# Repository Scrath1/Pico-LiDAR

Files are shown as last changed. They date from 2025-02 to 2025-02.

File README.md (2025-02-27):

# Pico-LiDAR
The goal of this project is to build a simple LiDAR sensor using hobbyist components
such as the Raspberry Pi Pico microcontroller, VL53L0X Time-of-Flight laser sensor
and the HC-SR04P ultrasonic sensor.



## Bill of Materials (BOM)
<details>
<summary>Mechanical Parts (click to open)</summary>

- 608Z bearing
- generic 6 wire slip ring with 12.5mm diameter
- 7x M4x10 bolts (can be shorter)
- 6x M3x16 countersunk bolts (can be shorter) for mounting the dome top cover
  and the base bottom plate to their respective bodies.
- 7-8x M3x4 bolts for mounting the L298N and XL6009 to the base plate as well as the
  slipring to the axis mount.
  but you don't really need to use them all. The remaining screws are for the XL6009.
- 4x M2x6 bolts for mounting the perfboard
- 2-4x M2x4 bolts for mounting the Pi Pico
- 2x M4 nuts
  I used one with a 9mm contracted length (measured without the end rings) and a
  filament diameter of 0.5mm. Stronger springs are also possible but it should
  not be much longer.
- 5x M4x8x6mm threaded insert
- 6x M3x6x5mm threaded insert
- 1x rubber band
- (optional) 1x short tension spring.
- 5x cylindrical magnets 10x6mm. If you want to use different magnets feel
  free to modify the provided 3D files. 4 are used for speed measurement.
  The 5th is for detecting the 0 degree position
</details>

<details>
<summary>Electronic Parts (click to open)</summary>

- generic RF-320 DC Motor
- XL6009 DC-DC Buck Boost Converter module
- L298N DC Motor Driver module
- Raspberry Pi Pico
- 2x A3144 Hall Effect Sensor or equivalent
  Note: The A3144 is a 5V sensor but in my experience will also work
  when powered using 3.3V.
- VL53L0X Time-of-Flight sensor module
- HC-SR04P Ultrasonic Sensor module (The P version can be powered from 3.3V)
- 6pin 2.54mm female socket connector for VL53L0X sensor
- 4pin 2.54mm female socket connector for HC-SR04P sensor
- 1 push button for manually starting the motor
- 1 push button for resetting the MCU (optional)
- 1 LED for indicating motor state and the corresponding current limiting resistor
- (Optional) 20pin IDC connector for JLink. Used for development purposes.
- 1x 70x30mm Perfboard. Used for mounting interfaces and power connectors.
  Can be slightly larger and can be cut up from a larger board as long
  as the holes for mounting are present.
- (Optional) ESP01 or other ESP8266-based controller for wireless connectivity
  using esp-link.
</details>

## Assembly instruction
Refer to the [Assembly instructions document](./docs/assembly.md)

## Setup
### Flashing using J-Link (SWD Mode)
**By default the project is configured to use a J-Link Debug Probe in SWD mode.
To use a Pico Debug Probe instead, switch out any reference to `jlink` in the `platformio.ini`
file for `raspberrypi-swd`. Using USB for flashing is not recommended since the USB port
will be inaccessible inside the case therefore preventing flashing new firmware later.**

Wire up the J-Link probe according to the following table.
| J-Link Pin | J-Link Pin Name | Pico Pin | Pico Pin Name  |
| --- | --- | --- | --- |
| 1 | VTref | 37 | 3V3 (OUT) |
| 4 | GND | 38 | GND |
| 5 | Tx (out) | 2 | GP1 / UART0_RX |
| 7 | SWDIO | | SWDIO |
| 9 | SWCLK | | SWCLK |
| 15 | nRESET | 30 | RUN |
| 17 | Rx (in) | 1 | GP0 / UART0_TX |
| 19 | 5V-Supply | 39 | VSYS |

**Warning: The 5V supply of the J-Link is insufficient to power the power the motor
and the pico. Connect a different power supply for the motor or the probe
will be unable to flash.**

**J-Link configuration:**
- The J-Link UART port has to be enable using the J-Link configurator utility
  if you have not done so already.
- The J-Link 5V-Supply pin is controlled using the J-Link commander utility.
  Use `power on` to turn it on or `power on perm` to make it stay on even after
  reconnecting the probe.

After setting up the J-Link you can flash the project using platformio.

### Installing dependencies for python script
To install the dependencies in a Python venv use the following commands
1. Create virtual environment
   > python -m venv .venv
2. Activate venv<br>
    Run the activation script in `.venv/Scripts/`corresponding to your platform
    from your current terminal. On windows that is either `activate.bat` or
    `Activate.ps1` depending on whether you use the command line or powershell.
    On linux use `activate` without any file extension.
3. Install dependencies from requirements.txt
   > pip install -r interface-script/requirements.txt

### Connections
Commands and communication from and to the LiDAR module are done using UART0
serial port of the pico, for which GP0 is the Tx pin and GP1 is Rx.

**Option 1: Connecting using USB serial adapter**

You can connect directly to the LiDAR module by using a USB serial adapter
connected to the aforementioned Rx and Tx pins.
The LiDAR uses a serial port configuration of 115200 baud 8N1.

The command for the interface script in that case would be.
> python interface-script/main.py -p \<serial-port>

Optionally you can specify the baudrate using `-b` but the default is set to
115200.

**Option 2: Wireless connection using esp-link**

When connecting to the device, either a USB serial adapter can be used, or an
ESP8266 module which was flashed using
[esp-link](https://github.com/jeelabs/esp-link)

The esp-link is again connected to the Rx and Tx pins using 115200 baud 8N1.
To connect the interface script to the esp-link use the `-d` parameter to specify
the devices hostname or ip-address.
> python interface-script/main.py -d \<hostname>

## Usage
### args file
All cli arguments you can pass to the interface script can also be written in a
plain text file to be passed to the program instead by using the `-f` parameter.

This is an example of what the content of this file could look like:
```
-p COM7
-r
-a 5000
```
The command to use this file would be
> python interface-script/main.py -f \<path to file>

## Attributions for CAD models
Unfortunately I did not keep track of the origin of 3D CAD models used
while building this project. If you think your model is being used and don't
want it to be, please open an issue and I will see about removing it.

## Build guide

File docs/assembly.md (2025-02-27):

# Assembly
**Required Tools:**
- Soldering Tools
- Heatgun
- Screwdrivers
- Hot glue

1. Installing heat-set inserts
   1. Base
    
    - Install 5x M4x8x6mm threaded inserts into the holes labeled with **1**.
    - Install 3x M3x6x5mm threaded inserts into the holes labeled with **2**.
   2. Dome
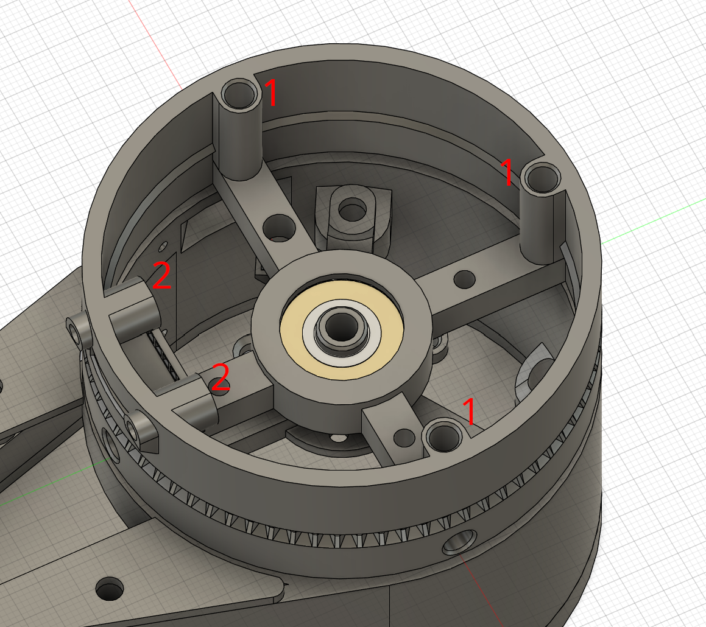
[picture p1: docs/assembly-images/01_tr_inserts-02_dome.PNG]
    
    - Install 3x M3x6x5mm threaded inserts into the holes labeled with **1**.
    - (Optional) Install 2x M3x6x5mm threaded inserts into the holes labeled with **2**.
2. Installing magnets<br>
   **Important:** Ensure the correct side of the magnets faces towards the hall
   effect sensors. To test this, put a hall effect sensor on a breadboard and connect
   its output to an LED. If the LED reacts when you hold a magnet close to the angled
   side of the hall effect sensor, mark that side using a permanent marker or similar
   and ensure that this side faces the sensor on the dome later.

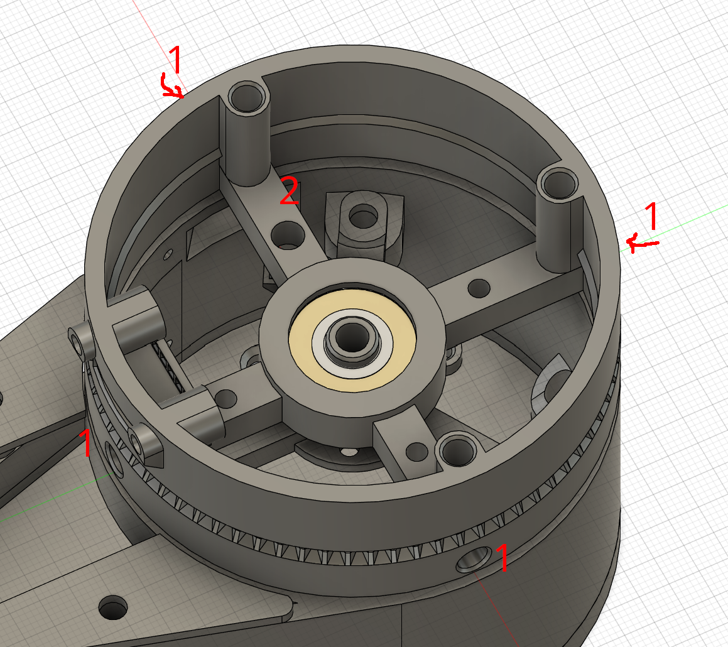
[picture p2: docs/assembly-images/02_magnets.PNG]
   
   - Using the heatgun, carefully heat up the holes for the magnets marked with **1**
     and push in the magnets with their marked side facing outward. If you don't know
     what is meant with marked side, read the note above the image.
    - Repeat the process from above with the hole marked with a **2** and have
     the marked  side facing downwards. Make sure the magnet does not extend out
     of the hole on the bottom.
3. Installing sensor sockets
   Install the 4pin and 6pin 2.54mm pinsockets as shown in the images by pushing them
   in from the front or top respectively. If you have clearance issues, again use the
   heatgun.
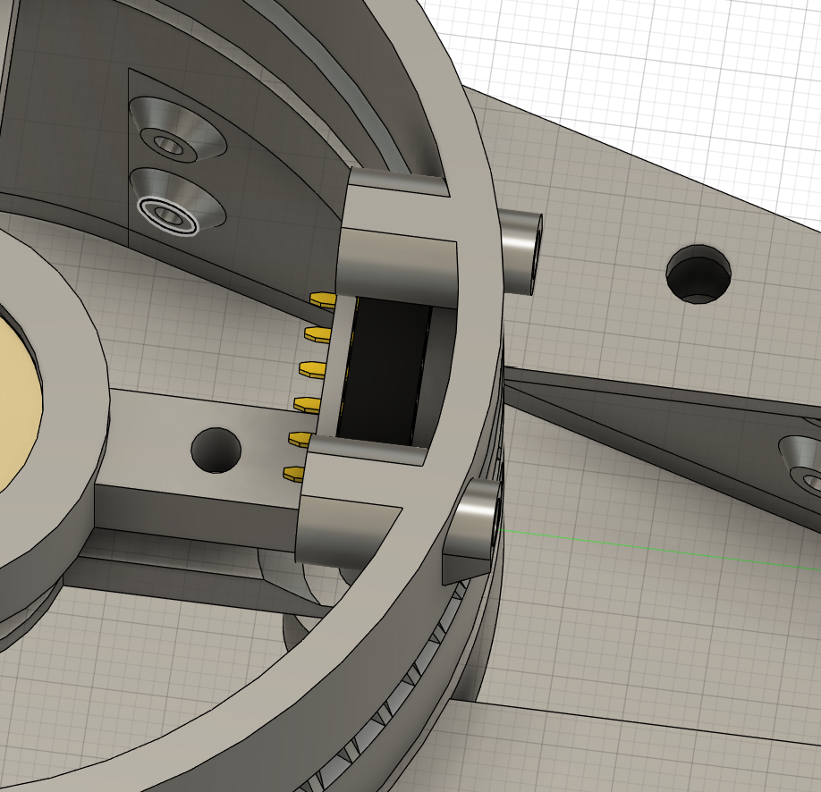
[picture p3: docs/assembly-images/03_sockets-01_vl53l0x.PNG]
   
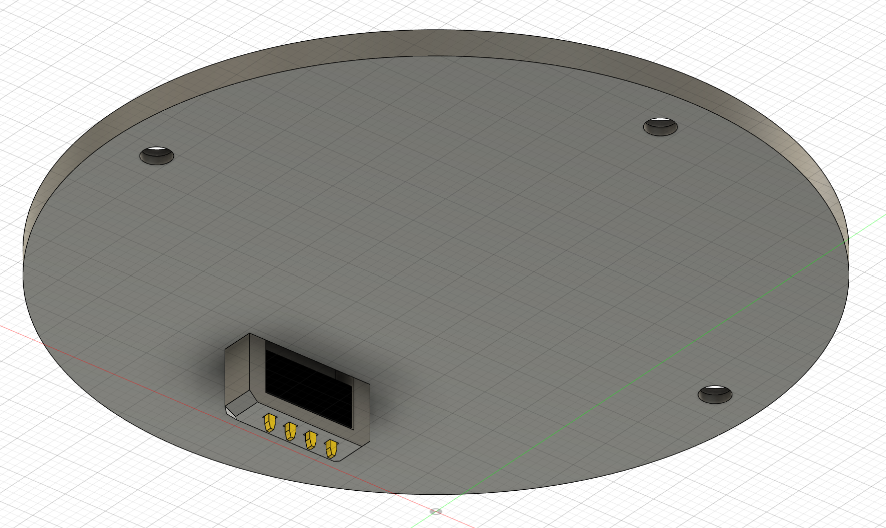
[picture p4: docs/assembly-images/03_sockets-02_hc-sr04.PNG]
   
4. Installing hall-effect sensors
   - Push one of the sensors through the small holes on the outside of the case.
     Make sure the angled side of the sensor faces towards the center of the sensor dome.
     If the holes were too small for the printer you can use a soldering iron to heat
     up the individual leads and melt new holes for the sensor into the plastic.
   - Solder some leads to the 2 hall effect sensors.
   - Secure the hall sensor mounted to the base using hotglue.
     
   - Mount the second sensor to the protrusion on the hollow axis-mount for the bearing.
     Again ensure the angled side is facing upwards.
     

5. Installing bearing and slipring
   - Press the bearing into the slot on the dome. If you have trouble with clearances,
     heat up the hole slightly using the heatgun to soften the plastic a bit before
     pushing the bearing in.
   - Repeat the process for the hollow axis shaft but be especially
     careful here to not overheat the plastic and deform it.
   - Pull the wires of the slipring through the hollow shaft with the rotating part
     facing towards the bearing and screw it into the plastic using 3x M3x4 screws.
    The final result should look something like this:
    
6. Solder the electronics according the circuit diagram.
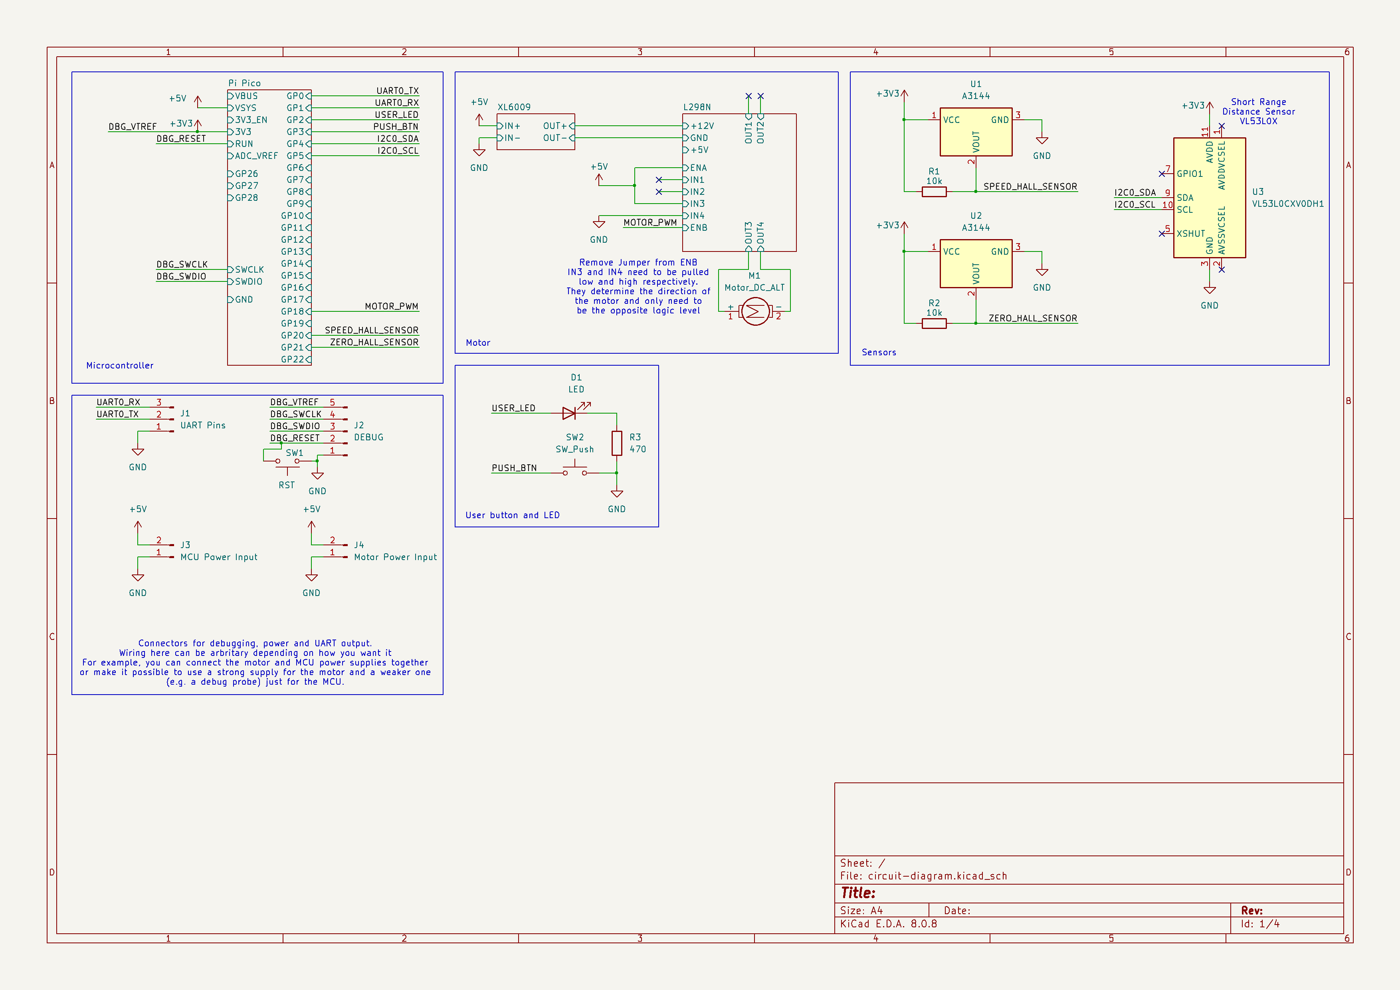
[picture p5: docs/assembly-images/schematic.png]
   
   I would recommend using as many connectors as possible to facilitate easier
   (dis-)assembly. Be mindful of the motor size when choosing connector locations.
   In some cases it may make sense to use a right angle connector.
   For reference, this is how I assembled my perfboard.
   
   
7. Mount the motor to its mounting bracket.
   Depending on which DC motor you get the mounting holes on the corresponding
   3D printed bracket may not line up. In that case you will need to edit the model
   yourself or drill fitting holes in the existing part.

   The 3D model is located in the [model](./model/) directory as a step file.
9. Push the driveshaft onto the motor motor shaft. Feel free to use the heatgun
   again here. Try and line it up as much as possible in height with the slot on the
   sensor dome assembly.
10. Mount the spring to the motor and the case using 2x M4x10 bolts and nuts.
    This part can be a bit finnicky.
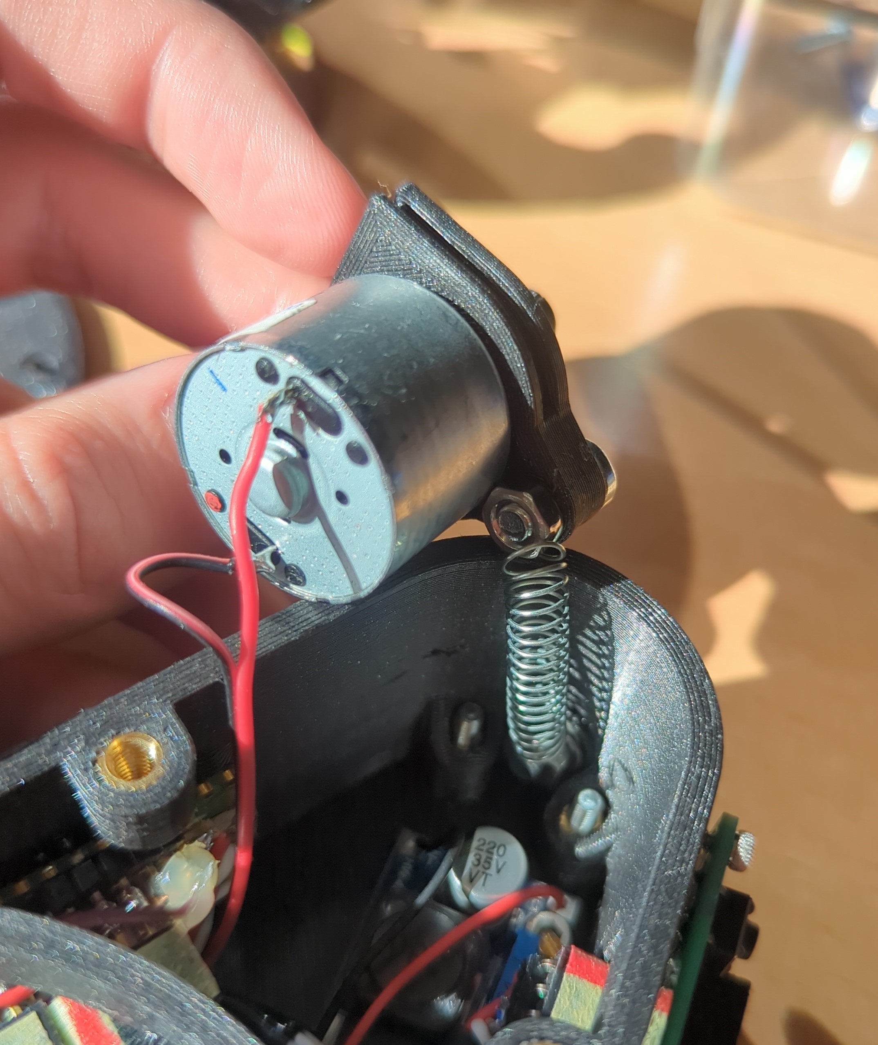
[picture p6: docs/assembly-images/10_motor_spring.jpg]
    
11. Mount the LM298N and Xl6009 boards to the baseplate using M3x4 bolts and
    the Pico to the wall of the base with 2x M2x4 bolts. Mount the baseplate using 3x M3x16 countersunk screws.
12. Plug everything in you can and mount the motor with the corresponding cover plate
    using another 2x M4x10 bolts. Make sure the motor can move more or less freely
    back and forth and isn't blocked by any wires.
13. Plug in the slipring and screw on the axis mount of the dome to the main body.
14. Screw in the dome cover plate and plug in the 2 sensors.

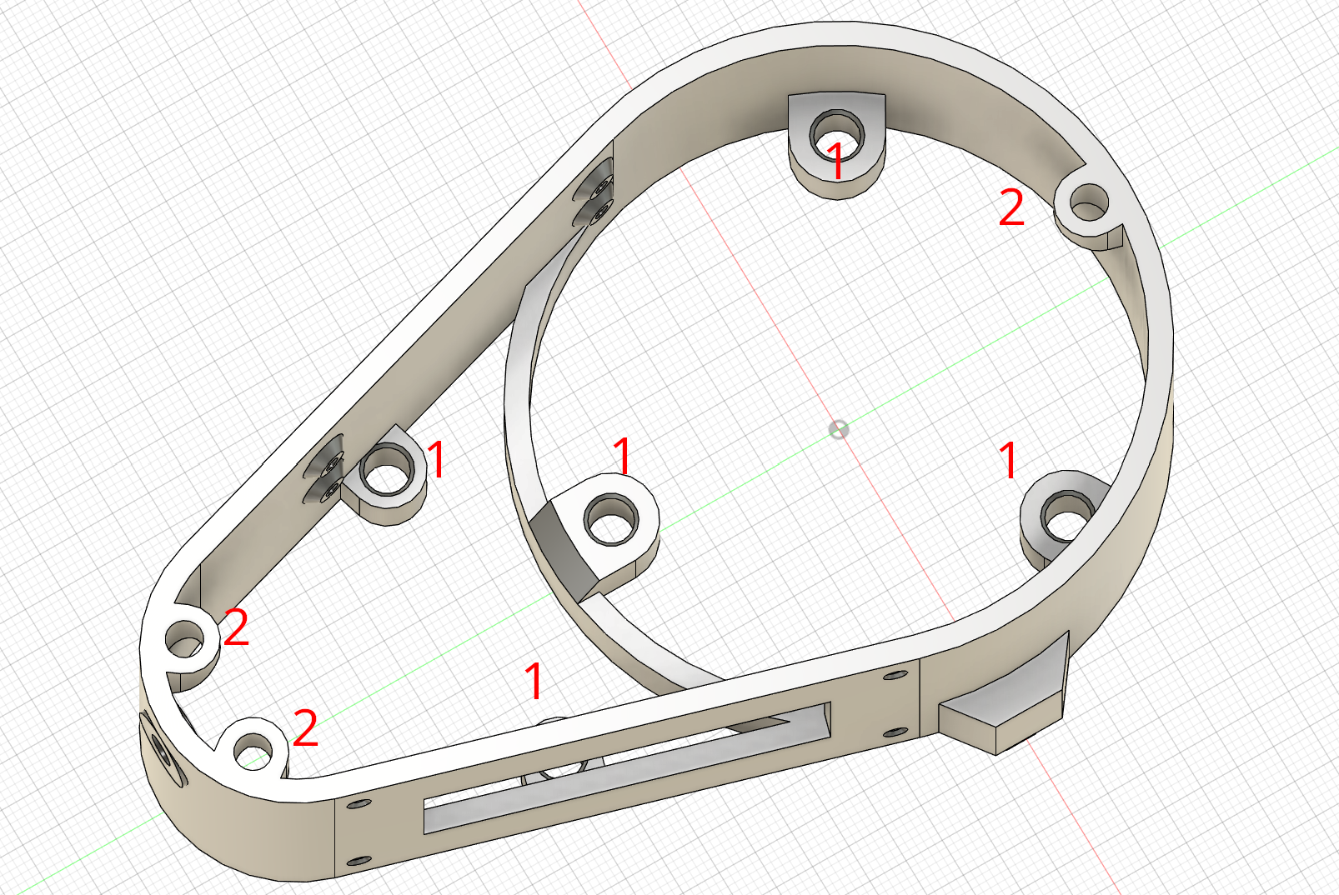
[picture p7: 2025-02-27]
docs/assembly-images/01_tr_inserts-01_base.PNG

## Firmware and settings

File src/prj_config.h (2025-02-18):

#ifndef PRJ_CONFIG_H
#define PRJ_CONFIG_H

// PIN CONFIGURATIONS
// ==============================================================
#define PIN_MOTOR_PWM (18)
#define PIN_SPEED_HALL_SENSOR (20)
#define PIN_ZERO_HALL_SENSOR (21)
#define PIN_PUSHBTN (3)
#define PIN_LED_USER (2)
#define PIN_ECHO (27)
#define PIN_TRIG (26)
#define LED_ON (1)
#define LED_OFF (0)
// debouncing time for buttons
#define BTN_DEBOUNCE_MS (100)

// COMMUNICATION
// ==============================================================
#define SERIAL_PORT Serial1

// MOTOR CONTROL CONFIGURATIONS
// ==============================================================
// Maximum target speed for the motor
#define MAX_TARGET_RPM (1000)
// Default motor rotation target speed
#define MOTOR_TARGET_SPEED (120)
// Defines the value which represents a PWM duty cycle of 100%
#define PWM_FULL_VALUE (16383)
// PID control P constant
#define K_P (1.6)
// PID control I constant
#define K_I (1.6)
// PID control D constant
#define K_D (0)
// Interval with which the PID control loop is run in milliseconds
#define PID_INTERVAL_MS (100)
// Minimum PID controller output value
#define PID_MIN_OUT (0)
// Maximum PID controller output value
#define PID_MAX_OUT (PWM_FULL_VALUE)
// Maximum PID constant value for very basic error checking purposes
#define PID_CONSTANT_MAX (10)
// Number of PID intervals over which the measured RPM has to be relatively
// constant before being declared stable
#define MEASURED_RPM_STABILITY_INTERVAL_COUNT (25)
// the +- range by which the measured RPM may differ from the
// target RPM over MEASURED_RPM_STABILITY_INTERVAL_COUNT PID control
// intervals for the speed to be considered stable
#define MEASURED_RPM_TOLERANCE (10)

// MOTOR SPEED MEASUREMENT CONFIGURATIONS
// ==============================================================
// Number of magnet pulses for a full rotation
#define PULSES_PER_REV 4
// Filter size for averaging of measured RPM
#define RPM_AVERAGING_FILTER_SIZE 4

// SERIAL INTERFACE CONFIGURATIONS
// ==============================================================
// Specifies the interval with which the serial task is run
#define SERIAL_INTERFACE_TASK_INTERVAL_MS (100)
// Specifies the interval with which runtime data such as the
// current speed and pwm value are printed to the console for plotting.\
// This value should be greater or equal to SERIAL_INTERFACE_TASK_INTERVAL_MS
#define SERIAL_INTERFACE_PLOT_OUTPUT_INTERVAL_MS (100)
// Determines the maximum length of a serial command in bytes
#define SERIAL_CMD_INPUT_BUFFER_SIZE (64)
// Time after which received serial data for commands is discarded if no
// new data was received and the command is incomplete.
#define SERIAL_CMD_INPUT_TIMEOUT_MS (105)
// Maximum length of a debug message
#define DBG_MESSAGE_MAX_LEN (256)
#define TX_BUFFER_LEN (10 * DBG_MESSAGE_MAX_LEN)

// SENSOR CONFIGURATION
// ==============================================================
// Determines how many different data points are acquired per full
// revolution of the dome. If this value is too high it may not be possible to reach
#define DEFAULT_SCANPOINTS_PER_REV (16)
// Maximum time in ms for the VL53L0X to measure a distance
#define VL53L0X_TIME_BUDGET_MS (20)
// How often the MCU tries to connect to the VL53L0X before ignoring it
// and only using the HC-SR04
#define VL53L0X_MAX_CONNECTION_ATTEMPTS (5)
// Maximum time to wait for the result of the HC-SR04 sensor.
// This time is in addition to the time budget of the VL53L0X sensor
// as the HC-SR04 is triggered first and read later
#define HC_SR04_TIME_BUDGET_MS (10)
// Extra time budget for each scan above the bare minimum
// required for getting the sensor readings. Increase if you get
// warnings about timing violations
#define SENSOR_SCAN_EXTRA_TIME_BUDGET_MS (12)
// Default offset by which to rotate any angle value
#define DEFAULT_ANGLE_OFFSET (-45)
// Distance of the HC-SR04 sensor from the the rotation center
#define HC_SR04_CENTER_OFFSET_MM (35)
// Distance of the VL53L0X sensor from the the rotation center
#define VL53L0X_CENTER_OFFSET_MM (44)

// SIGNAL AGE
// ==============================================================
// How often the task checking the age of signals is executed
#define SIGNAL_AGE_CHECK_INTERVAL_MS (25)
// How old the measuredRPM signal is allowed to be before it is invalidated
#define SIGNAL_MEASURED_RPM_AGE_THRESHOLD_MS (300)

#endif  // PRJ_CONFIG_H

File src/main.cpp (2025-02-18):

#include <Arduino.h>
#include <FreeRTOS.h>
#include <hardware/gpio.h>
#include <hardware/pwm.h>
#include <pico/stdlib.h>
#include <task.h>
#include <ulog.h>

#include "averaging_filter.h"
#include "global.h"
#include "macros.h"
#include "prj_config.h"
#include "serial_print.h"
#include "spid.h"
#include "tasks/motor_control_task.h"
#include "tasks/sensor_task.h"
#include "tasks/serial_interface_task.h"
#include "tasks/serial_tx_task.h"
#include "tasks/signal_age_check_task.h"

AVERAGING_FILTER_DEF(measuredRPMFilter, RPM_AVERAGING_FILTER_SIZE);

void consoleLogger(ulog_level_t severity, char* msg) {
    char fmsg[DBG_MESSAGE_MAX_LEN];
    uint32_t len = snprintf(fmsg, sizeof(fmsg), "%10lu [%s]: %s\n", pdTICKS_TO_MS(xTaskGetTickCount()),
                            ulog_level_name(severity), msg);
    serialPrint(fmsg, len + 1);
}

void hallSensorISR(uint32_t events) {
    if(events & GPIO_IRQ_EDGE_FALL) {
        static uint32_t lastPulseTime_us = 0;
        static uint32_t pulseIntervals[PULSES_PER_REV] = {0};
        const uint32_t pulseIntervalsArrSize = sizeof(pulseIntervals) / sizeof(pulseIntervals[0]);
        // points to next index to write to
        static uint32_t pulseIntervalsNextIdx = 0;

        // immediately acquire timestamp of pulse
        const uint32_t currentTime_us = time_us_32();

        // read
        dome_angle_t da = status.domeAngle;
        // modify
        uint16_t newAngleBase;
        if(!gpio_get(PIN_ZERO_HALL_SENSOR)) {
            // Zero angle detected
            newAngleBase = 0;
        } else {
            newAngleBase = (da.angleBase + (360 / PULSES_PER_REV)) % 360;
        }
        dome_angle_t newAngPos = {.angleBase = newAngleBase, .timeOfAngleIncrement_us = currentTime_us};
        // write back
        status.domeAngle = newAngPos;

        // initialize variable before measuring
        if(lastPulseTime_us == 0) {
            lastPulseTime_us = time_us_32();
            return;
        }
        // calculate time between the last 2 magnetic pulses
        const uint32_t interval_us = currentTime_us - lastPulseTime_us;
        lastPulseTime_us = currentTime_us;

        // calculate actual axle rotation speed
        static uint32_t rpmMeasurements[RPM_AVERAGING_FILTER_SIZE];
        static const uint32_t rpmMeasurementsSize = sizeof(rpmMeasurements) / sizeof(rpmMeasurements[0]);
        static uint32_t rpmMeasurementsNextIdx = 0;
        // Step 1. Calculate pulse interval in seconds instead of microsends
        float calc = static_cast<float>(interval_us) / 1E6;
        // Step 2. Multiply with amount of magnets per full rotation
        calc *= PULSES_PER_REV;
        // Step 3. Calculate frequency of rotation (Rotations per second)
        calc = 1 / calc;
        // Step 4. Calculate RPM from rotation frequency
        const uint32_t currentRPMMeasurement = calc * 60;

        // Average RPM and apply the averaged value to the measuredRPM status signal
        averaging_filter_put(&measuredRPMFilter, currentRPMMeasurement);
        status.measuredRPM.setFromISR(averaging_filter_get_avg(&measuredRPMFilter));
    }
}

void pushBtnLeftISR() {
    static uint32_t lastTriggerTime_ms = 0;
    const uint32_t currentTime_ms = pdTICKS_TO_MS(xTaskGetTickCountFromISR());
    if(currentTime_ms - lastTriggerTime_ms > BTN_DEBOUNCE_MS) {
        // button isn't bouncing (anymore)
        runtimeSettings.enableMotor.set(!runtimeSettings.enableMotor.get());
    }
    lastTriggerTime_ms = currentTime_ms;
}

void gpio_callback(uint gpio, uint32_t events) {
    BaseType_t xHigherPriorityTaskWoken = pdFALSE;
    if(gpio == PIN_SPEED_HALL_SENSOR)
        hallSensorISR(events);
    else if(gpio == PIN_PUSHBTN)
        pushBtnLeftISR();
    else if(gpio == PIN_ECHO){
        if(events & GPIO_IRQ_EDGE_FALL) hc_sr04_isr(xHigherPriorityTaskWoken, false);
        else hc_sr04_isr(xHigherPriorityTaskWoken, true);
    }

    if(xHigherPriorityTaskWoken) {
        portYIELD_FROM_ISR(pdTRUE);
    }
}

void configurePins() {
    gpio_init(PIN_LED_USER);
    gpio_set_dir(PIN_LED_USER, GPIO_OUT);
    gpio_set_drive_strength(PIN_LED_USER, GPIO_DRIVE_STRENGTH_12MA);
    gpio_put(PIN_LED_USER, LED_OFF);

    gpio_init(PIN_SPEED_HALL_SENSOR);
    gpio_set_dir(PIN_SPEED_HALL_SENSOR, GPIO_IN);
    // Hall effect sensors already have a pull-up resistor soldered to them
    gpio_set_irq_enabled_with_callback(PIN_SPEED_HALL_SENSOR, GPIO_IRQ_EDGE_FALL | GPIO_IRQ_EDGE_RISE, true,
                                       gpio_callback);

    gpio_init(PIN_ZERO_HALL_SENSOR);
    gpio_set_dir(PIN_ZERO_HALL_SENSOR, GPIO_IN);
    // Hall effect sensors already have a pull-up resistor soldered to them

    gpio_init(PIN_PUSHBTN);
    gpio_set_pulls(PIN_PUSHBTN, true, false);
    gpio_set_dir(PIN_PUSHBTN, GPIO_IN);
    // only first gpio irq to be configured has to use gpio_set_irq_enabled_with_callback
    gpio_set_irq_enabled(PIN_PUSHBTN, GPIO_IRQ_EDGE_FALL, true);

    gpio_init(PIN_TRIG);
    gpio_set_pulls(PIN_TRIG, false, true);
    gpio_set_dir(PIN_TRIG, GPIO_OUT);

    gpio_init(PIN_ECHO);
    gpio_set_pulls(PIN_ECHO, false, true);
    gpio_set_dir(PIN_ECHO, GPIO_IN);
    gpio_set_irq_enabled(PIN_ECHO, GPIO_IRQ_EDGE_FALL | GPIO_IRQ_EDGE_RISE, true);

    gpio_set_function(PIN_MOTOR_PWM, GPIO_FUNC_PWM);
    uint8_t pwmSlice = pwm_gpio_to_slice_num(PIN_MOTOR_PWM);
    uint8_t pwmChan = pwm_gpio_to_channel(PIN_MOTOR_PWM);
    pwm_set_wrap(pwmSlice, PWM_FULL_VALUE);
    pwm_set_chan_level(pwmSlice, pwmChan, 0);
    pwm_set_enabled(pwmSlice, true);
}

void setup() {
    // put your setup code here, to run once:

    // Initialize the logger
    ULOG_INIT();
    ULOG_SUBSCRIBE(consoleLogger, ULOG_TRACE_LEVEL);

    // Set up serial
    SERIAL_PORT.setTX(0);
    SERIAL_PORT.setRX(1);
    SERIAL_PORT.begin(115200);

    averaging_filter_init(&measuredRPMFilter);

    // Pin configuration
    ULOG_TRACE("Setup: Configuring pins");
    configurePins();

    // create tasks
    ULOG_TRACE("Setup: Creating tasks");
    ULOG_TRACE("Setup: Switching to Tx task for serial output");
    volatile bool txTaskReady = false;
    if(pdPASS != xTaskCreateAffinitySet(serialTxTask, SERIAL_TX_TASK_NAME, SERIAL_TX_TASK_STACK_SIZE,
                                        (void*)(&txTaskReady), SERIAL_TX_TASK_PRIORITY, SERIAL_TX_TASK_CORE_MASK,
                                        &serialTxTaskHandle)) {
        ULOG_CRITICAL("Setup: Failed to create serial Tx task");
        configASSERT(false);
    }
    while(!txTaskReady) {
        vTaskDelay(pdMS_TO_TICKS(10));
    }
    useTxTask = true;
    ULOG_TRACE("Setup: Switch to Tx task done");

    if(pdPASS != xTaskCreate(motorControlTask, MOTOR_CONTROL_TASK_NAME, MOTOR_CONTROL_TASK_STACK_SIZE, NULL,
                             MOTOR_CONTROL_TASK_PRIORITY, &motorCtrlTaskHandle)) {
        ULOG_CRITICAL("Setup: Failed to create motor control task");
        configASSERT(false);
    }
    vTaskCoreAffinitySet(motorCtrlTaskHandle, (1 << 0));

    if(pdPASS != xTaskCreate(signalAgeCheckTask, SIGNAL_AGE_CHECK_TASK_NAME, SIGNAL_AGE_CHECK_TASK_STACK_SIZE, NULL,
                             SIGNAL_AGE_CHECK_TASK_PRIORITY, &signalAgeCheckTaskHandle)) {
        ULOG_CRITICAL("Setup: Failed to create signal age check task");
        configASSERT(false);
    }
    vTaskCoreAffinitySet(signalAgeCheckTaskHandle, (1 << 0));
    if(pdPASS != xTaskCreate(serialInterfaceTask, SERIAL_INTERFACE_TASK_NAME, SERIAL_INTERFACE_TASK_STACK_SIZE, NULL,
                             SERIAL_INTERFACE_TASK_PRIORITY, &serialInterfaceTaskHandle)) {
        ULOG_CRITICAL("Setup: Failed to create serial interface task");
        configASSERT(false);
    }
    vTaskCoreAffinitySet(signalAgeCheckTaskHandle, (1 << 0));
    if(pdPASS != xTaskCreate(sensorTask, SENSOR_TASK_NAME,
                             SENSOR_TASK_STACK_SIZE, NULL,
                             SENSOR_TASK_PRIORITY, &sensorTaskHandle)) {
        ULOG_CRITICAL("Setup: Failed to create sensor task");
        configASSERT(false);
    }
    vTaskCoreAffinitySet(sensorTaskHandle, (1<<0));

    ULOG_TRACE("Setup: finished");
    vTaskDelete(NULL);
    taskYIELD();
    // This is done in the background by the arduino-pico core already
    // vTaskStartScheduler();
}

void loop() {}

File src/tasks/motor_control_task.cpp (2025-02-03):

#include "motor_control_task.h"

#include <hardware/pwm.h>
#include <ulog.h>

#include "prj_config.h"
#include "spid.h"

TaskHandle_t motorCtrlTaskHandle;

// Copies of settings objects
static setting<float> pid_kp;
static setting<float> pid_ki;
static setting<float> pid_kd;
static setting<uint32_t> targetRPM;
static setting<bool> enableMotor;

#define TASK_LOG_NAME ("MotorTsk")

void rpmToleranceCheck() {
    const uint32_t tgt = targetRPM.get();

    uint32_t minMeasuredRPM;
    if(tgt > MEASURED_RPM_TOLERANCE){
        minMeasuredRPM = tgt - MEASURED_RPM_TOLERANCE;
    }
    else{
        minMeasuredRPM = 0;
    }
    uint32_t maxMeasuredRPM;
    if(tgt < UINT32_MAX - MEASURED_RPM_TOLERANCE){
        maxMeasuredRPM = tgt + MEASURED_RPM_TOLERANCE;
    }
    else{
        maxMeasuredRPM = UINT32_MAX;
    }
    if(minMeasuredRPM <= status.measuredRPM.rpm && status.measuredRPM.rpm <= maxMeasuredRPM) {
        status.stableTargetRPMCount++;
    } else {
        status.stableTargetRPMCount = 0;
    }
    if(status.stableTargetRPMCount >= MEASURED_RPM_STABILITY_INTERVAL_COUNT && !status.stableTargetRPM) {
        status.stableTargetRPM = true;
        ULOG_DEBUG("%s: measured RPM turned stable", TASK_LOG_NAME);
        // rpmWithinToleranceIntervalsCnt may eventually overflow but with
        // it being a uint32_t that should be a long long long time
    } else if(status.stableTargetRPMCount < MEASURED_RPM_STABILITY_INTERVAL_COUNT && status.stableTargetRPM) {
        status.stableTargetRPM = false;
        ULOG_DEBUG("%s: measured RPM turned unstable", TASK_LOG_NAME);
    }
}

void motorControlTask(void* pvParameters) {
    ULOG_TRACE("%s: Starting", TASK_LOG_NAME);
    // Copies of settings objects
    pid_kp = runtimeSettings.pid_kp;
    pid_ki = runtimeSettings.pid_ki;
    pid_kd = runtimeSettings.pid_kd;
    targetRPM = runtimeSettings.targetRPM;
    enableMotor = runtimeSettings.enableMotor;

    // Initialize PID controller
    spid_t pid;
    if(SPID_SUCCESS !=
       spid_init(&pid, pid_kp.get(), pid_ki.get(), pid_kd.get(), PID_MIN_OUT, PID_MAX_OUT, PID_INTERVAL_MS)) {
        ULOG_CRITICAL("%s: Failed to initialize PID controller", TASK_LOG_NAME);
        configASSERT(false);
    }

    // get channel and slice number of the PWM slice used for the motor pin
    const uint8_t pwmChannelNum = pwm_gpio_to_channel(PIN_MOTOR_PWM);
    const uint8_t pwmSliceNum = pwm_gpio_to_slice_num(PIN_MOTOR_PWM);

    TickType_t lastWakeTime = xTaskGetTickCount();
    ULOG_TRACE("%s: Starting loop", TASK_LOG_NAME);
    for(;;) {
        // First check for setting updates
        if(pid_kp != runtimeSettings.pid_kp) {
            // ULOG_INFO("%s: %s changed: %0.3f -> %0.3f", TASK_LOG_NAME, pid_kp.name, pid.k_p, runtimeSettings.pid_kp);
            pid_kp = runtimeSettings.pid_kp;
            spid_set_kp(&pid, pid_kp.get());
        }
        if(pid_ki != runtimeSettings.pid_ki) {
            // ULOG_INFO("%s: %s changed: %0.3f -> %0.3f", TASK_LOG_NAME, pid_ki.name, pid.k_i, runtimeSettings.pid_ki);
            pid_ki = runtimeSettings.pid_ki;
            spid_set_ki(&pid, pid_ki.get());
        }
        if(pid_kd != runtimeSettings.pid_kd) {
            // ULOG_INFO("%s: %s changed: %0.3f -> %0.3f", TASK_LOG_NAME, pid_kd.name, pid.k_d, runtimeSettings.pid_kd);
            pid_kd = runtimeSettings.pid_ki;
            spid_set_kd(&pid, pid_kd.get());
        }
        if(targetRPM != runtimeSettings.targetRPM) {
            targetRPM = runtimeSettings.targetRPM;
        }
        if(enableMotor != runtimeSettings.enableMotor) {
            enableMotor = runtimeSettings.enableMotor;
        }

        // measured rpm stability check
        rpmToleranceCheck();
        uint16_t pwm;
        uint32_t pidRPMTarget;
        if(enableMotor.get()) {  // if motor enable is on
            pwm = (uint16_t)spid_process(&pid, (float)targetRPM.get(), status.measuredRPM.rpm);
            gpio_put(PIN_LED_USER, LED_ON);
        } else {
            spid_process(&pid, (float)0, status.measuredRPM.rpm);
            pwm = 0;
            gpio_put(PIN_LED_USER, LED_OFF);
        }
        status.pwmOutputLevel = pwm;
        pwm_set_chan_level(pwmSliceNum, pwmChannelNum, pwm);

        // Preempt task until next loop iteration time
        xTaskDelayUntil(&lastWakeTime, pdMS_TO_TICKS(PID_INTERVAL_MS));
    }
}

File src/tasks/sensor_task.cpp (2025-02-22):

#include "sensor_task.h"

#include <VL53L0X.h>
#include <Wire.h>
#include <queue.h>
#include <ulog.h>

#include "global.h"
#include "prj_config.h"
#include "serial_print.h"

#define VL53L0X_TIMEOUT_MS 50

#define SPEED_OF_SOUND_MPS (343)
#define HC_SR04_TRIG_PULSE_DURATION_US (10)

#define TASK_LOG_NAME ("SensorTsk")

TaskHandle_t sensorTaskHandle;

// local setting copies
static setting<uint32_t> targetRPM;
static setting<uint32_t> vl53l0xTimingBudget_us;
static setting<uint16_t> dataPointsPerRev;
static setting<int16_t> angleOffset;

// Queue for sending measured pulse duration of HC-SR04 sensor in us
// to the actual sensor task
QueueHandle_t hc_sr04_pulseDurationQueue;

uint32_t rpmToTimePerRev_ms(uint16_t rpm) { return (1000 / (rpm / 60)); }

// Calculates the minimum time to set aside for sampling at each datapoint
// Based on the timing budget of the sensors + some configurable tolerance
// (SENSOR_SCAN_EXTRA_TIME_BUDGET_MS)
uint32_t getMinSampleTime_ms(uint32_t vl53l0x_budget_ms) {
    return vl53l0x_budget_ms + SENSOR_SCAN_EXTRA_TIME_BUDGET_MS + HC_SR04_TIME_BUDGET_MS;
}

// calculate the maximum time that can ideally be spent for each sample point.
// Based on the current target RPM and the number of sample points
uint32_t getMaxSampleTime_ms(uint16_t rpm, uint32_t samplePoints) { return (rpmToTimePerRev_ms(rpm)) / samplePoints; }

uint16_t checkMaxScanpointsPerRev(uint16_t rpm, uint32_t samplePoints, uint32_t vl53l0x_budget_ms) {
    // reduce the number of sample points until the minimum time required to sample
    // is below the maximum time available for each range sample
    while(true) {
        if(samplePoints == 0) return 0;
        uint32_t t_min = getMinSampleTime_ms(vl53l0x_budget_ms);
        uint32_t t_max = getMaxSampleTime_ms(rpm, samplePoints);
        if(t_min > t_max)
            samplePoints--;
        else
            break;
    }
    return samplePoints;
}

void hc_sr04_isr(BaseType_t& xHigherPriorityTaskWoken, bool risingEdge) {
    static uint32_t timeOfRisingEdge_us = 0;
    if(risingEdge) {
        timeOfRisingEdge_us = time_us_32();
    } else {
        if(timeOfRisingEdge_us != 0) {
            uint32_t currentTime_us = time_us_32();
            uint32_t duration = currentTime_us - timeOfRisingEdge_us;
            xQueueSendFromISR(hc_sr04_pulseDurationQueue, &duration, &xHigherPriorityTaskWoken);
        }
    }
}

int64_t reset_trig_pin(alarm_id_t id, void* user_data) {
    (void)user_data;
    gpio_put(PIN_TRIG, false);
    return 1;
}

void sensorTask(void* pvParameters) {
    ULOG_TRACE("%s: Starting", TASK_LOG_NAME);

    VL53L0X vl53l0x;
    Wire.begin();
    vl53l0x.setTimeout(VL53L0X_TIMEOUT_MS);
    bool vl53l0xInitialized = false;
    for(uint32_t i = 0; i < VL53L0X_MAX_CONNECTION_ATTEMPTS; i++) {
        if(vl53l0x.init()) {
            ULOG_INFO("%s: VL53L0X initialized", TASK_LOG_NAME);
            vl53l0xInitialized = true;
            break;
        } else {
            ULOG_ERROR("%s: Attempt %lu failed to initialize VL53L0X sensor. Retrying in 1s", TASK_LOG_NAME, i + 1);
            vTaskDelay(pdMS_TO_TICKS(1000));
        }
    }
    if(!vl53l0xInitialized){
        ULOG_WARNING("%s: Could not initialize VL53L0X. Ignoring that sensor", TASK_LOG_NAME);
    }

    hc_sr04_pulseDurationQueue = xQueueCreate(4, sizeof(uint32_t));
    if(NULL == hc_sr04_pulseDurationQueue) {
        ULOG_CRITICAL("%s: Failed to create HC-SR04 pulse duration queue", TASK_LOG_NAME);
        configASSERT(false);
    }
    // Ranging profiles for VL53L0X
    // +---------------+---------------+---------------------+----------------------------------------+
    // |     Mode      | Timing Budget |  Typical Max Range  |           Typical applicaton           |
    // +---------------+---------------+---------------------+----------------------------------------+
    // | Default       | 30ms          | 1.2m (white target) | standard                               |
    // | High accuracy | 200ms         | 1.2m (white target) | precise measurement                    |
    // | Long range    | 33ms          | 2m (white target)   | long ranging, only for dark conditions |
    // | High Speed    | 20ms          | 1.2m (white target) | high speed, accuracy is no priority    |
    // +---------------+---------------+---------------------+----------------------------------------+
    // Operating modes
    // 1. Single ranging: Only one measurement is taken
    // 2. Continuous: Back to back measuring as fast as possible
    // 3. Timed: Back to back measuring with a fixed delay between measurements

    TickType_t lastWakeTime = xTaskGetTickCount();
    ULOG_TRACE("%s: Starting loop", TASK_LOG_NAME);
    for(;;) {
        // Check for setting updates. The local copies are used so that
        // changes in other tasks to the global objects are less likely to mess
        // up some calculations here
        if(targetRPM != runtimeSettings.targetRPM) {
            targetRPM = runtimeSettings.targetRPM;
        }
        if(vl53l0xTimingBudget_us != runtimeSettings.vl53l0xMeasurementTimingBudget_us) {
            vl53l0xTimingBudget_us = runtimeSettings.vl53l0xMeasurementTimingBudget_us;
            if(vl53l0xInitialized) {
                vl53l0x.setMeasurementTimingBudget(vl53l0xTimingBudget_us.get());
            }
        }
        if(dataPointsPerRev != runtimeSettings.dataPointsPerRev) {
            dataPointsPerRev = runtimeSettings.dataPointsPerRev;
        }
        if(angleOffset != runtimeSettings.angleOffset) {
            angleOffset = runtimeSettings.angleOffset;
        }

        // ToDo: Maybe outsource this step to another point
        uint16_t checkedMaxScanpoints =
            checkMaxScanpointsPerRev(targetRPM.get(), dataPointsPerRev.get(), vl53l0xTimingBudget_us.get() / 1000);
        if(checkedMaxScanpoints < dataPointsPerRev.get() || status.sensorTaskInterval_ms == 0) {
            runtimeSettings.dataPointsPerRev.set(checkedMaxScanpoints);
            uint32_t rotationPeriod_ms = rpmToTimePerRev_ms(targetRPM.get());
            uint32_t taskInterval_ms = rotationPeriod_ms / checkedMaxScanpoints;
            status.sensorTaskInterval_ms = taskInterval_ms;
            ULOG_WARNING("%s: Sample rate unattainable. Reduced scanpoints to %u", TASK_LOG_NAME, checkedMaxScanpoints);
        }

        // Actual range reading
        // 1. Trigger the HC-SR04 ultrasonic sensor
        gpio_put(PIN_TRIG, true);
        // 2. Set callback alarm to reset trigger after its trigger interval
        sleep_us(HC_SR04_TRIG_PULSE_DURATION_US);
        gpio_put(PIN_TRIG, false);

        // 2. Read the VL53L0X laser sensor
        uint16_t vl53l0x_range_mm = 0;
        if(vl53l0xInitialized) vl53l0x_range_mm = vl53l0x.readRangeSingleMillimeters() + VL53L0X_CENTER_OFFSET_MM;
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

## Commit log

2025-01-17 PID control working relatively good
2025-01-19 Added filtering for targetRPM
2025-01-19 Added FreeRTOS und ulog lib files
2025-01-20 Added KiCAD project for later creating the circuit diagram
    [circuit-diagram.kicad_pcb, circuit-diagram.kicad_sch]
2025-01-22 Started work on circuit diagram
    [circuit-diagram.kicad_sch, l298n.kicad_sch, pico.kicad_sch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]
2025-01-22 Rework to use global objects rather than parameters passed by reference
    [global.cpp, main.cpp, motor_control_task.cpp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]
2025-01-22 Switched back to using parameter based signals
    The bug causing the targetRPM value to not be sent to the console was a layer 8 issue. Before this commit, the motor enable switch had to be on for the targetRPM to be printed to the console
    [main.cpp, motor_control_task.cpp]
2025-01-23 Switch to hardware based PWM
2025-01-24 Added function for building serial frames
2025-01-25 Created separate rx thread for interface script
2025-01-25 Added push button for sending motor enable signal
2025-01-25 Fixed serial command parsing bug Bug occurred when multiple commands would be send without break causing the framesize counter to be too large beginning from the second command
    [serial_commands.cpp]
2025-01-25 Reading motor state from device working
2025-01-26 GUI parameter parsing from serial working
    Switched to using human readable messages only in replies from microcontroller
2025-01-26 Switch to publisher subscriber model for data point messages
2025-01-26 Rudamentary plot working
    Bug detected in requesting data from MCU. Values don't always match
    [main.py, serial_interface.py]
2025-01-26 Bugfixes
    - Fixed wrong data being retrieved from queues in python script
    - Fixed program not exiting after window was closed
    [main.py, serial_commands.cpp, serial_interface.py]
2025-01-26 Minor bug fixes in python script and quality of life
    - Fixed various crashes by correctly handling exceptions
    - Removed auto sending of control values and added send button
    [main.py, prj_config.h, serial_interface.py]
2025-01-27 Removed motor enable switch and old potentiometer pin definition
2025-01-27 Added measured RPM stability check
    [main.cpp, motor_control_task.cpp, prj_config.h]
2025-01-27 Renamed Serial port macro to avoid conflicts
    [main.cpp, prj_config.h, sensor_task.cpp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]
2025-01-29 Schematic update
    also removed unneeded import from python script
    [circuit-diagram.kicad_sch]
2025-01-29 Major rework
    - Removed signals and parameter passing to task to simplify data structures
    - Note: This commit contains parts of the next commit already. All parts with serialPrint are effected
    [dome_angle.h, global.cpp, main.cpp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]
2025-01-30 Added hall sensor for zero angle detection
2025-01-31 UART using separate serial tx task working
2025-01-31 Fixed motor target rpm update not applying, added better log tracing
    [main.cpp, motor_control_task.cpp, sensor_task.cpp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]
2025-02-01 Added plotting of PWM duty cycle to PID GUI
2025-02-01 Tuning and sensor task changes
    - Changed PWM counter range
    - Re-enabled sensor task
    - Fixed calculation of sensor task intervals
    - Added probably unnecessary range checks to rpm tolerance check
    - Updated default PID and targetRPM values for a speed of 150 RPM
    [global.cpp, main.cpp, motor_control_task.cpp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]
2025-02-01 Fixed bugs in dome angle calculation
    - Bug 1 was the base angle not being updated in the hall effect interrupt
    - Bug 2 was an overflow in the angle calculation function due to integer division instead of float
    [dome_angle.h, main.cpp, sensor_task.cpp]
2025-02-01 Improved lidar plotting
2025-02-03 Moved to normal Pi Pico MCU, Changed pinout, Reused user LED
2025-02-03 Enabled graceful closing of GUI when lidar plot is closed
2025-02-03 Added maximum age parameter to lidar plotting
2025-02-03 Updated README and schematic
    [circuit-diagram.kicad_sch]
2025-02-05 Fixed missing tick to time macros
    [main.cpp]
2025-02-06 Serial Interface Rework
    - Changed format of serial command frames to fixed-length to prevent accidental frame end delimiters
    - Updated Serial command parsing to use state machine for better readability
    - Added support for more configuration (e.g. angle offset, vl53l0x time budget) via serial interface
    - Added Reset command
    - Added serial error counter to check for successful execution of commands
    [dome_angle.h, global.cpp, main.py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]
2025-02-06 Moved reset to be a seperate command rather than a set parameter
    [serial_commands.cpp, serial_commands.h, serial_interface.py]
2025-02-08 Rework of python gui using Qt underway
    [gui.py, main.py, sensor_task.cpp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]
2025-02-09 Added run-length-encoding of RPM and PWM data in GUI to save memory
2025-02-09 Added maximum age to lidar plotting via CLI parameter
2025-02-16 Raised PID computation range and fixed race condition in interface script
    [interface.py, prj_config.h]
2025-02-16 Added sensor center offset calculation and reduced target speed further
2025-02-16 Switched GUI to use polar plot instead of converting readings to coordinates
2025-02-18 Fixed Bug in GUI and serial interfaces causing sensor options to not be displayed
    [interface.py, serial_commands.cpp, serial_commands.h]
2025-02-18 Added display for latest sensor readings, enabled pull-downs for HC-SR04 pins
2025-02-18 Reduced PWM frequency to eliminate whining noise
    [prj_config.h]
2025-02-18 Fix RPM calculation error
    [main.cpp]
2025-02-22 Fixed bug causing MCU to hang with targetRPM speeds below 120
    Bug was caused due to a low target rpm speed with low datapoints not triggering the sensor task interval calculation thereby leaving a uninitialized sensor task interval of 0 which causes the sensor task to continuously execute without leaving time for any other task
    [sensor_task.cpp]
2025-02-27 Updated requirements.txt and fixed argparse help text errors
    [main.py]
2025-02-27 Created assembly instructions
2025-02-27 Added picture of final LiDAR module
